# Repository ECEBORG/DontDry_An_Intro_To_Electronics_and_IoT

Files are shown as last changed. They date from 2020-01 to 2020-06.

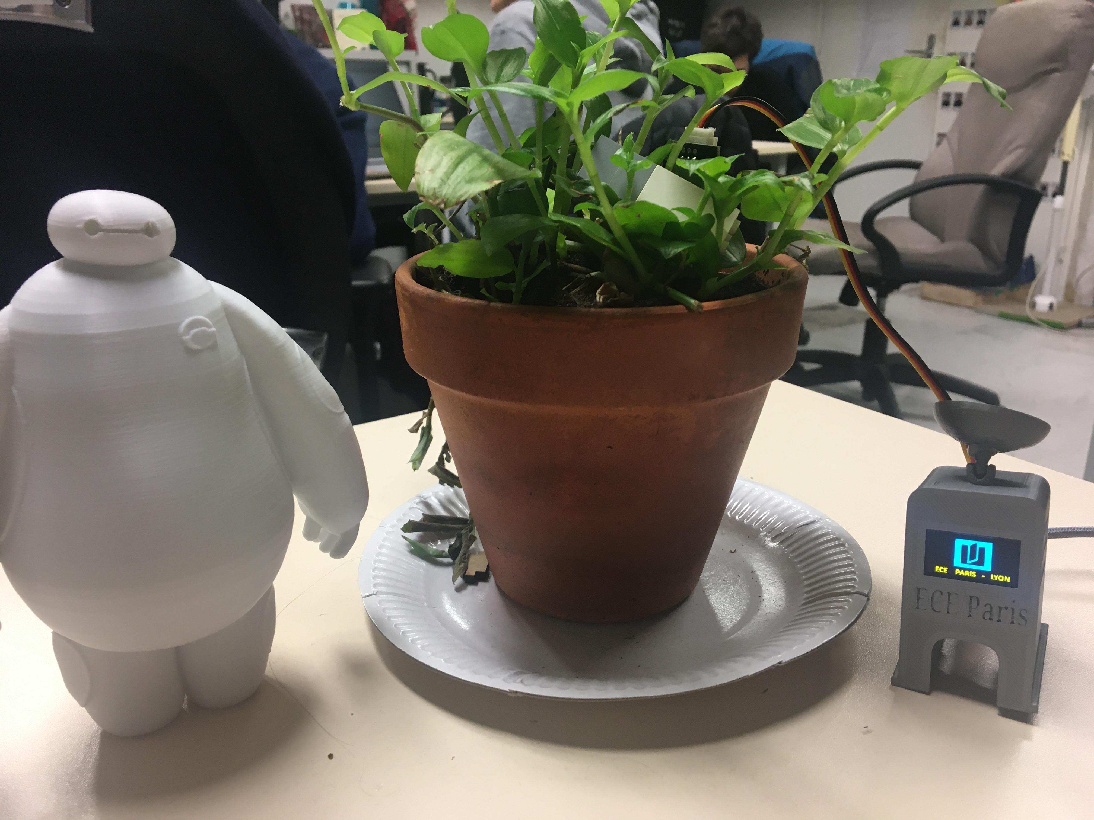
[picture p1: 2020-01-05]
Illustration dont dry.jpg

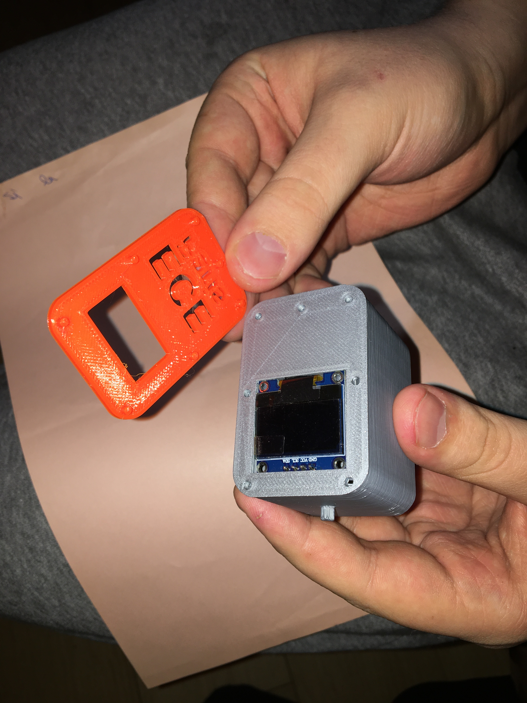
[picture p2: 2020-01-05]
Photos d'illustration/IMG_9418.JPG

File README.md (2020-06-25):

# ECEBORG - Projet "Don't dry"

_Beginner's Electronics project - plant monitoring tool_

> Ce projet a été organisé en Decembre 2019 par Nicolas Chollet avec l'aide de Lucie Pignol, Chloé Leca-Labouillerie, Maelys Bourgeat, Clément Couillerot & Benoit Montazeaud.

Le projet don't Dry est un atelier pour faire découvrir le monde des microcontroleur, de l'IoT et de l'électronique à des débutants.
Il contient trois activités:

* Soudure et montage d'une **petite station connectée permettant de lire la température, l'humidité de l'air et l'humidité du sol**.
* Cours d'introduction aux systèmes embarqués et à l'IoT
* Visite du fablab de l'ece et du hackerspace d'Eceborg

## Dans ce dossier vous trouverez :
* **Administratif** : Tout ce qui est relatif à l'organisation du projet
* **BitMaps** : Les images à afficher sur l'écran du projet
* **Code_Dont_Dry** : Il s'agit du code à flasher sur la carte, il est commenté.
* **STL** : Les fichiers Stl à télécharger pour le boitier
* **Support de présentations** : Les powerpoint utilisés pendant l'introduction, le cours sur les SE et la visite d'Eceborg
* **Tutoriels Arduino & Montage** : Tuto sur l'installation d'Arduino et le montage du projet à partir du Kit
* Un **descriptif de l'atelier**

Pour toute questions n'hésitez pas à contacter Eceborg:
eceborg.paris.bureau@assos.ece.fr
ou sur notre page facebook, twitter, instagram: [@eceborg](https://facebook.com/Eceborg/)

Merci beaucoup!

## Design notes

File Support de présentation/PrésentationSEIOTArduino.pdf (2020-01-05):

## UNE INTRODUCTION AU MONDE DES SYSTEMES

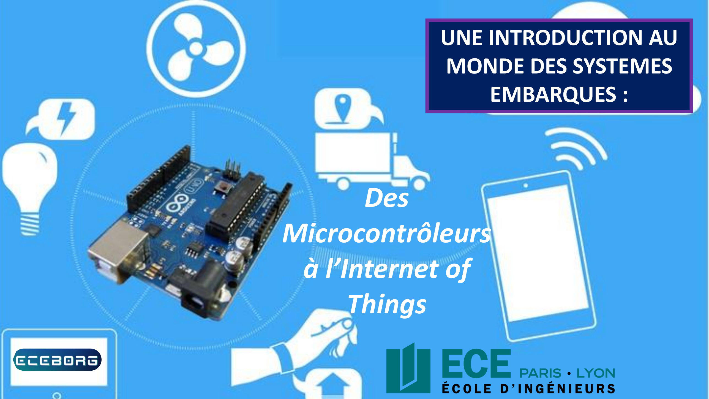
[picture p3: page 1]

## EMBARQUES :

# Des Microcontrôleurs à l’Internet of Things

# Système embarquoi?

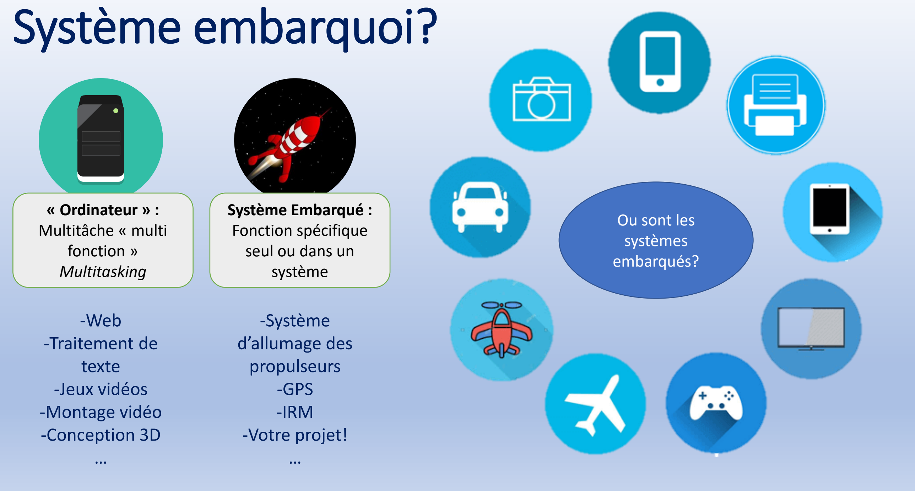
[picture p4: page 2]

Ou sont les
systèmes
embarqués?

« Ordinateur » :
Multitâche « multi
fonction »
Multitasking

Système Embarqué :
Fonction spécifique
seul ou dans un
système

-Web
-Traitement de
texte
-Jeux vidéos
-Montage vidéo
-Conception 3D
…

-Système
d’allumage des
propulseurs
-GPS
-IRM
-Votre projet!
…

# Internet

Of

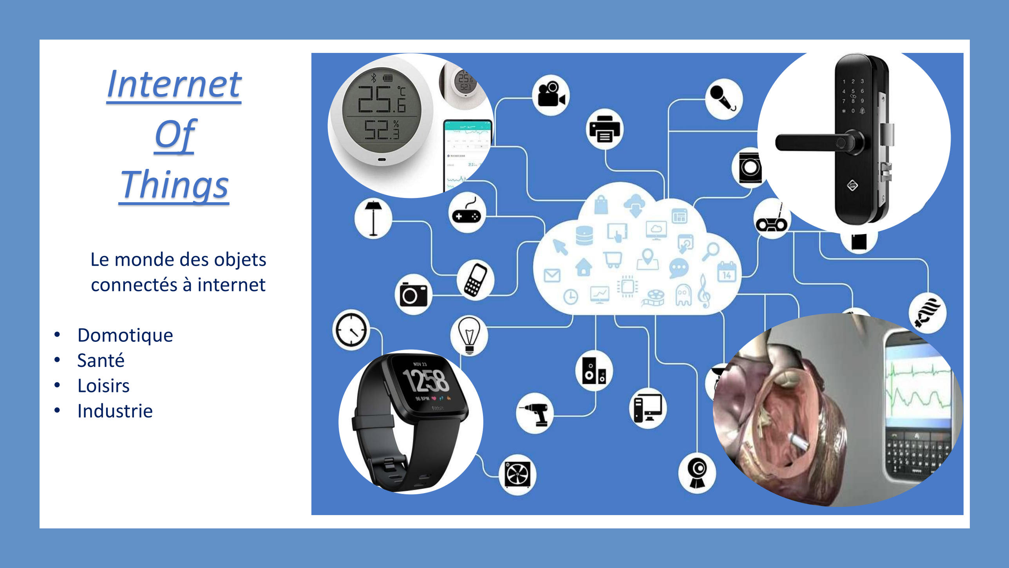
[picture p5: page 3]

# Things

Le monde des objets
connectés à internet
- Domotique
- Santé
- Loisirs
- Industrie

## La troisième révolution du Web

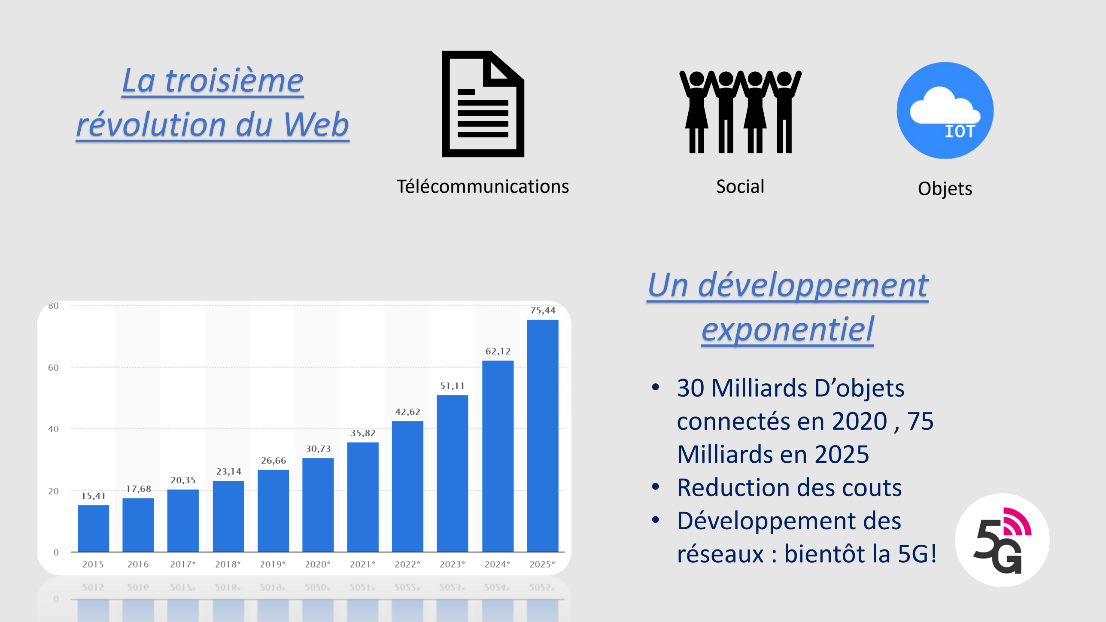
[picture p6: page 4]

### - 30 Milliards D’objets connectés en 2020 , 75 Milliards en 2025 - Reduction des couts - Développement des réseaux : bientôt la 5G!

## Un développement exponentiel

Télécommunications | Social | Objets

## MCU: MicroController Unit : Microcontrôleur

## CPU: Central Processing Unit

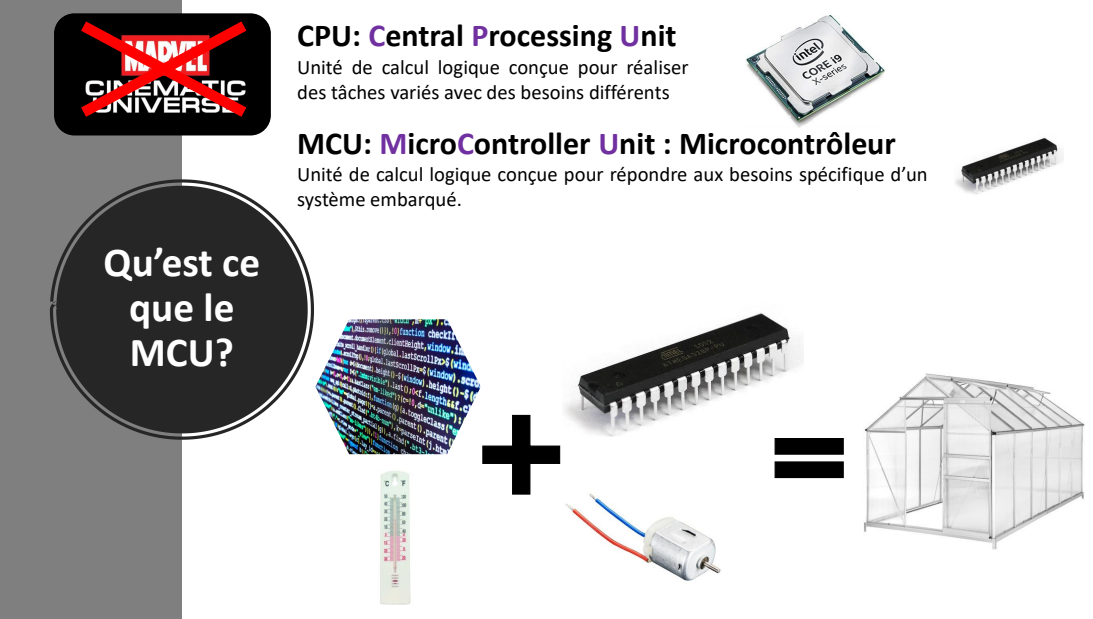
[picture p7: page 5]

Unité de calcul logique conçue pour réaliser
des tâches variés avec des besoins différents

Unité de calcul logique conçue pour répondre aux besoins spécifique d’un
système embarqué.

Qu’est ce
que le
MCU?

# La genèse d’Arduino

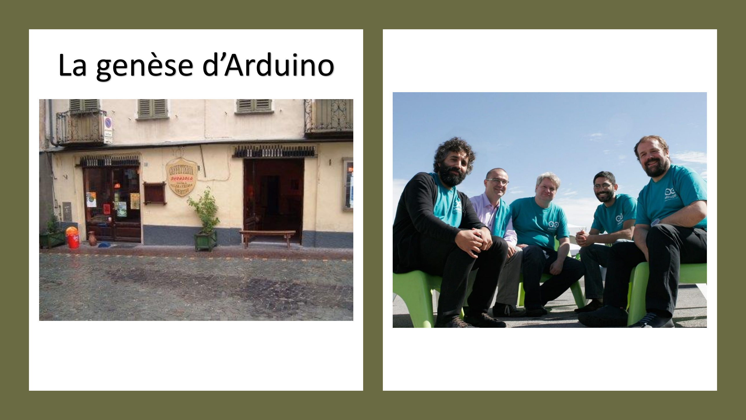
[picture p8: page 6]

# L’Arduino ou le microcontrôleur

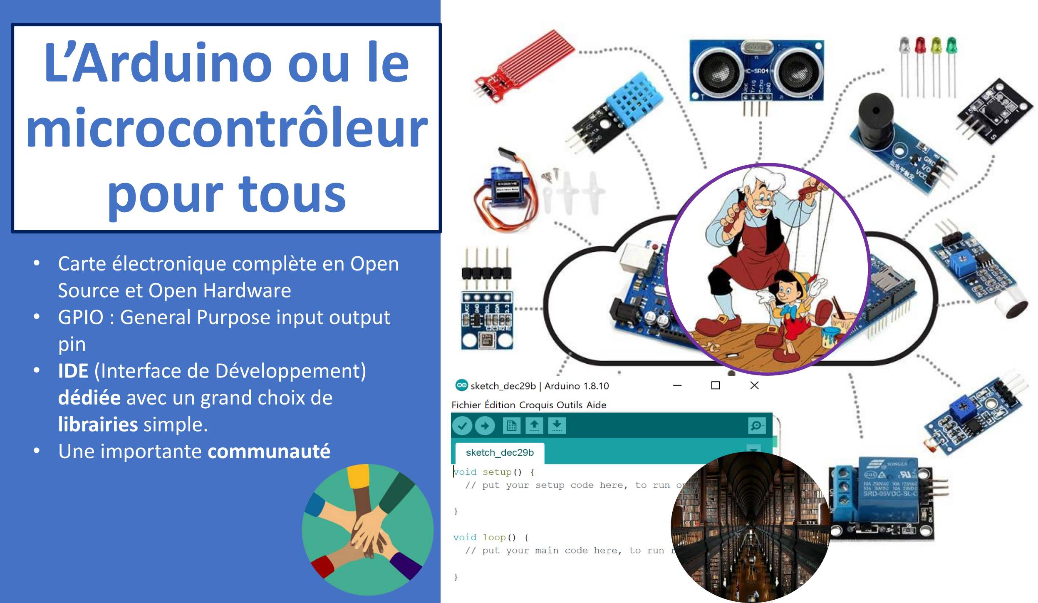
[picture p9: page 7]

# pour tous

- Carte électronique complète en Open Source et Open Hardware
- GPIO : General Purpose input output pin
- IDE (Interface de Développement) dédiée avec un grand choix de librairies simple.
- Une importante communauté

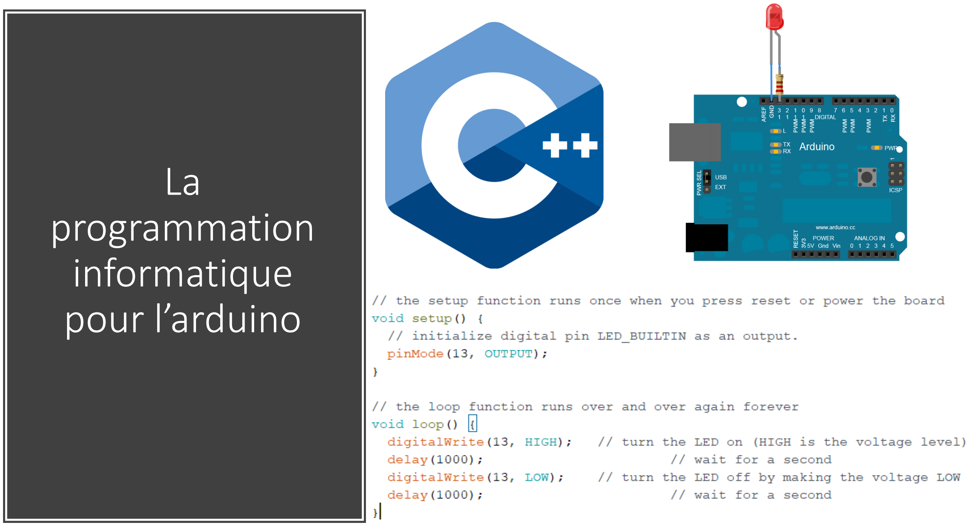
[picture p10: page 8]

La

# programmation informatique pour l’arduino

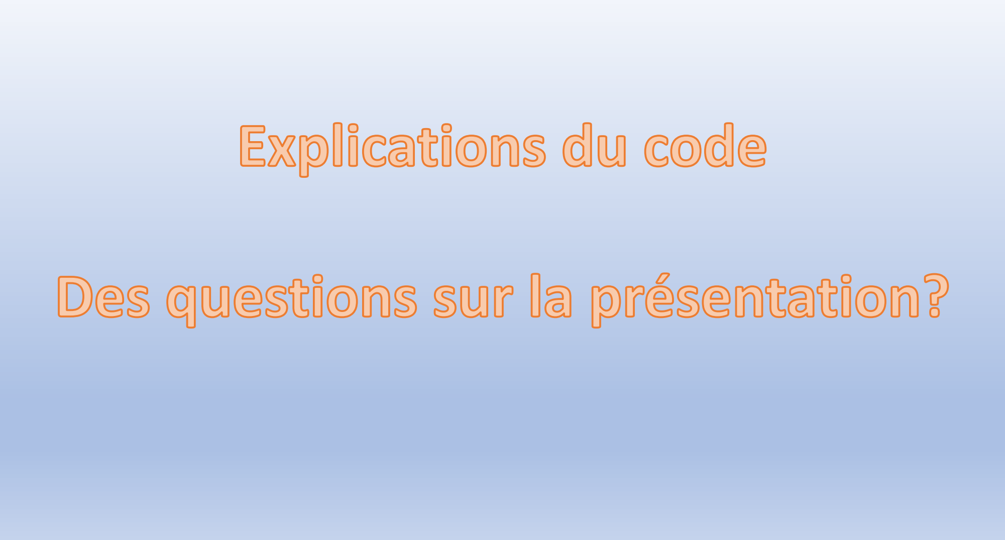
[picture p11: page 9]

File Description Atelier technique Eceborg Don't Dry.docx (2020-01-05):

Atelier technique Eceborg

Session admission 2020

Don’t Dry

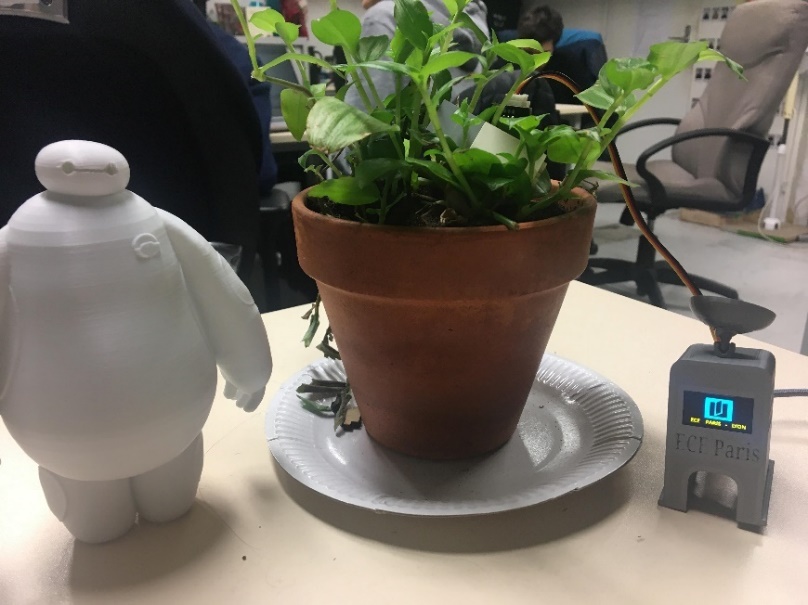
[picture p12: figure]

# I. Objet de ce document

Ce document a pour but de fournir des explications claires et précises concernant la réalisation du projet « don’t dry » dans le cadre des sessions admissions de 2020. Il est destiné aux organisateurs de cet atelier.

# II. Introduction

En Janvier et Février 2020, l’ECE organise trois sessions admissions où l’école accueille 180 élèves de terminale et première afin de leur faire découvrir l’école (60 par session). Dans ce contexte, Eceborg a été sollicité pour réaliser un atelier créatif pour initier ces élèves à l’électronique et au travail d’ingénieur. Cet atelier invite les participants à construire leur propre station connectée pour les aider à la gestion de l’arrosage d’une plante plante afin de découvrir le monde de l’IoT (Internet Of Things). Cet objet sera capable de :

- Afficher la température ambiante
- Afficher l’humidité de l’air
- Indiquer s’il faut arroser la plante ou non
- Indiquer l’heure
- Fournir ces informations via un site web local
- Envoyer une alerte mail quand il faut arroser la plante

L’idée est de fournir le code et le matériel aux élèves et de les accompagner pour les soudures, l’assemblage et le flashage du code.

# III. Description technique du projet

## A. Composants

- Microcontrôleur : Wemos D1 mini

Datasheet: https://wiki.wemos.cc/products:d1:d1_mini

Ce microcontrôleur fonctionne comme un Arduino mais dispose d’une puce esp8266 qui lui permet de se connecter en Wifi.

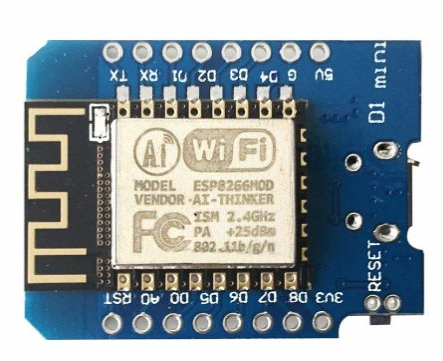
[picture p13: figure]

- Ecran : Afficheur OLED 0,96'' contrôlé en I2C

Datasheet : https://cdn-shop.adafruit.com/datasheets/SSD1306.pdf

Cet écran permet d’écrire sur 4 lignes différentes lisiblement.

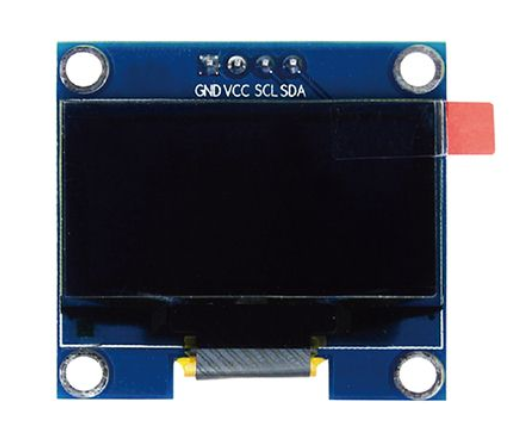
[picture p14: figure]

- Capteur d’humidité et de température : DHT11

Datasheet : https://www.mouser.com/datasheet/2/758/DHT11-Technical-Data-Sheet-Translated-Version-1143054.pdf

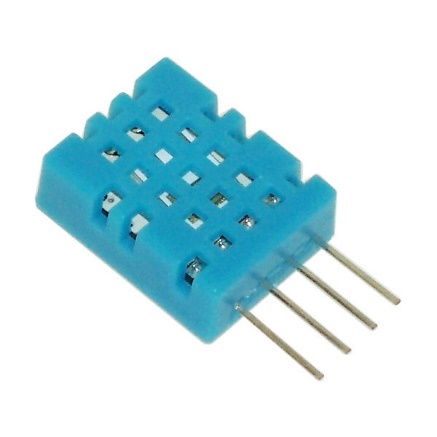
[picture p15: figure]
Résultat de recherche d'images pour "dht11"

- Capteur d’humidité des sols :

Datasheet : https://www.electroschematics.com/arduino-soil-moisture-sensor-module/

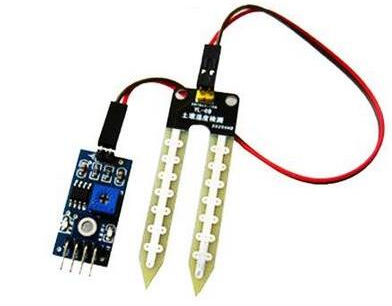
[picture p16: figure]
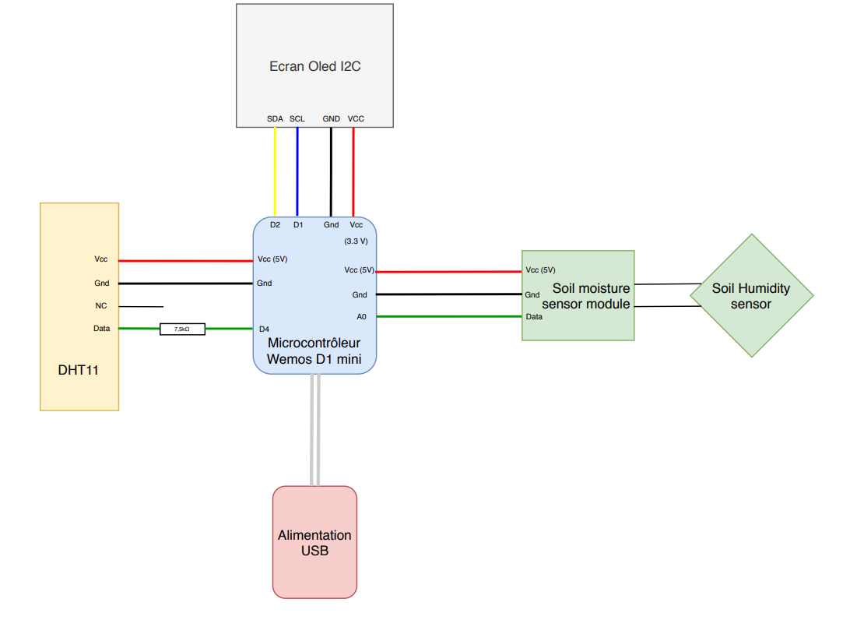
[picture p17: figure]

## B. Schéma fonctionnelle

Ce schéma représente les connections à effectuer entre les différents composants. Chaque fil a un code couleur et sera fourni avec les composants déjà découpé à la bonne taille. Il suffira juste de souder chaque fil à l’endroit indiqué.

Attention ce schéma contient une erreur au niveau des Pins de la DHT11. Regardez google pour la position exact des pins et de la résistance (en pull up).

## C. Code

Le Code est déjà réalisé et commenté. Il est communiqué en annexe de cette présentation. Pour sa bonne exécution il faut installer plusieurs librairies :

- Adafruit_SSD1306.h : Bibliothèque de fonctions pour l'écran Oled 128x64
- DHT.h : Bibliothèque de fonctions pour le capteur de température et d'humidité DT11
- NTPClient.h : Bibliothèque pour la gestion de l’heure
- ESP8266WiFi.h : Bibliothèque pour la gestion de la connexion internet
- WiFiUdp.h : Bibliothèque pour la gestion de la connexion internet

Sur ce lien vous pourrez trouver un tutoriel pour installer une librairie sur Arduino :

https://www.arduino.cc/en/guide/libraries

## D. Coque

La coque est imprimée en 3D. Pour le moment un design est proposé aux élèves et potentiellement d’autres seront créés d’ici le début de la session. Toutes les coques sont conçues dans le même but : pourvoir insérer les différents composants en les clipsant de manière simple et rapide. Les coques seront imprimées en amont de la session immersion.

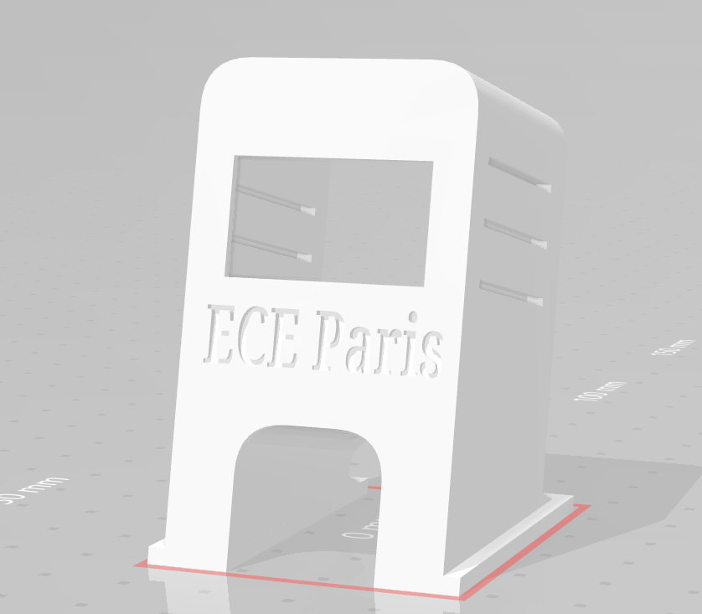
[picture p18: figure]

## E. Résumé

La réalisation du projet se déroule donc en trois étapes :

1. Soudure des composants
2. Flashage du code sur le microcontrôleur
3. Assemblage des composants dans le boitier

# IV. Répartition des élèves.

Les groupes des élèves visitant l’ECE sont composés de 60 élèves. Pour faciliter la mise en place des ateliers ils seront séparés en 4 groupes de 15 élèves qui seront chacun accompagné par 5 accompagnateurs de l’ECE pour la bonne réalisation du projet. Chaque groupe de 15 effectuera le même programme.

# V. Rôle des accompagnants

## A. Organisation globale et déroulement

L’atelier débute à 14H15. Le rendez vous est fixé en P445 ou Nicolas Chollet fera une brève présentation du projet aux 60 élèves ainsi que le déroulement de l’atelier. Après la présentation, les élèves seront emmenés par groupe de 15 par 5 accompagnateurs. Chaque groupe dispose d’une salle dans laquelle sera installé une paillasse pour les travaux d’électronique.

Dans chaque groupe de 15 donc, les élèves devront alterner entre trois ateliers en groupe de 5 :

- Atelier électronique 40 minutes : soudure des composants, dans la salle du groupe.
- Atelier informatique 40 minutes : explication du monde de l’Arduino (20 min) puis explication du code et flashage du code sur les cartes (20min), dans la salle du groupe.
- Atelier découverte du fablab et d’Eceborg (40 min) : Visite du fablab (20 min), visite du hackerspace d’ECEborg (20 min).

Pour conclure tous les groupes seront ramené à 16H30 dans la P445 pour un mot de conclusion de la part de Nicolas Chollet.

## B. Electronicien

Les accompagnateurs électroniciens auront la charge de l’atelier électronique. Ils seront deux par salle (8 au total). Leur rôle est d’accompagner 5 étudiants à la fois pour réaliser toutes les soudures en 40 min pour les 5 étudiants et de finir les soudures de ceux qui n’auraient pas été assez rapide. Ils disposeront d’un document imprimé précisant chaque étape avec photos et indications pratique. Ces accompagnateurs seront également formés en réalisant une première fois l’atelier en amont du jour J.

Profil recherché pour le poste électronicien : 2 personnes

- Sait faire des soudures ou est prêt à apprendre
- Disponible à un moment pendant les vacances de noël pour venir réaliser le projet (du coup on repart avec le projet).
- Manuel (enfin un minimum mais encore une fois c’est très basique juste quelques soudures)

## C. Chef de salle

Le rôle du chef de salle est minime il accompagne juste les élèves jusqu’à leur salle après l’introduction en p445, il est attentif au timing. A la fin des ateliers il rassemble les 15 élèves de sa salle et les raccompagne en p445. Le chef de salle n’est pas un rôle à 100% et il vient s’ajouter à un autre rôle (électronicien ou informaticien)

## D. Informaticien

Les accompagnateurs informaticiens réalisent une présentation PowerPoint sur l’Arduino, les microcontrôleurs et le code en C++. Ils sont au nombre de deux. La présentation est composée de slides qui leur seront fournies ainsi que les informations à communiquer à chaque slide. La présentation dure 20-25 minutes en fonction des questions. Par la suite ils réalisent une démo pour montrer l’installation de l’IDE Arduino et explique rapidement le code du projet en indiquant les parties que les élèves peuvent modifier chez eux. Enfin ils flash le code sur les microcontrôleurs des élèves.

Ces élèves assisteront en amont à la présentation pour bien comprendre et être capable de la reproduire. Ce sera surement par Skype ou via une vidéo YouTube. Cette présentation sera disponible avant noël.

Profil recherché pour le poste informaticien : 2 personnes

- A l’aise à l’oral
- Capable de ramener son ordinateur le jour de la soutenance
- Connait plus ou moins l’IDE Arduino ou est prêt a subir une petite formation en plus pour bien comprendre.

## E. Guide & Présentateur

Les guides, sont au nombre de deux. Toutes les 40 min il viennent chercher 5 élèves de deux salles différentes soit 10 élèves au total pour les emmener à la visite du fablab puis à la visite de Eceborg. Ils auront un document leur indiquant leur parcours étapes par étapes.

Profil recherché pour les guides :

- Avoir des pieds
- Être jovial pour discuter avec les élèves sur le chemin

Les présentateurs sont au nombre de deux : un a Eceborg et un au fablab. Ils réalisent la présentation de ces deux lieux, plus du mécanisme de l’impression 3D (à eceborg) et de la découpe laser (fablab). C’est à cette occasion qu’ils récupèrent un badge ece découpé au laser ainsi que le boitier pour leur prototype.

Ces rôles seront assurés par Benoit Montazeau (Eceborg) et Sébastien Ye (makers).

## F. Récapitulatif

- Accueil en P445 entre 14H et 14H15
- Présentation du projet + répartition des 60 élèves en 4 groupes de 15 dans 4 salles différentes.
- Répartition des groupes en trois sous-groupes de 5 élèves qui se répartissent sur les trois ateliers dans chaque salle : électronique, informatique, visite et début à 14H30.
- Changement d’atelier toutes les 40 minutes soient à 15H10 et 16H50
- Mot de la fin et conclusion en P445 (10 min) à 16H30.

# VI. Besoins logistiques

Chaque salle a besoin :

- 1 Projecteur
- 4 fers à souder
- 1 bobine d’étain
- 15 kits du projet Don’t Dry
- 1 pinces à dénuder
- 1 pompe à dessouder + du fil à dessouder
- 1 seringue de flux
- 4 troisièmes mains
- 3 pinces plates
- 2 pinces coupantes
- 1 ensemble de gaine thermo rétractable.
- 1 kit de fils
- Des feuilles & stylo

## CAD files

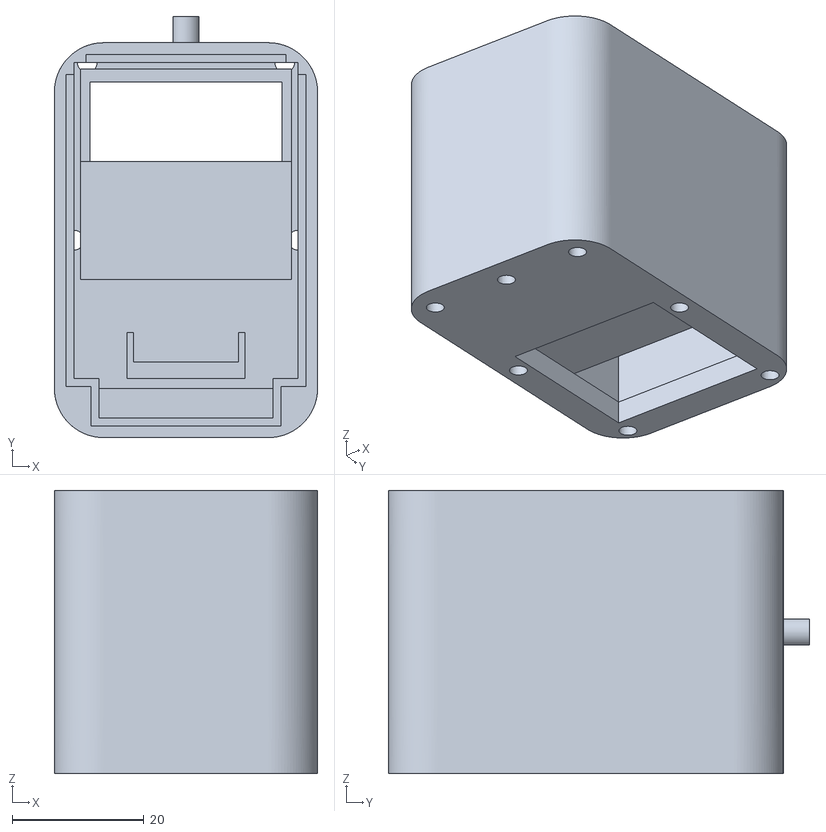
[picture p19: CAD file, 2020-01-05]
STL/Body.stl
40.0 x 64.0 x 43.0

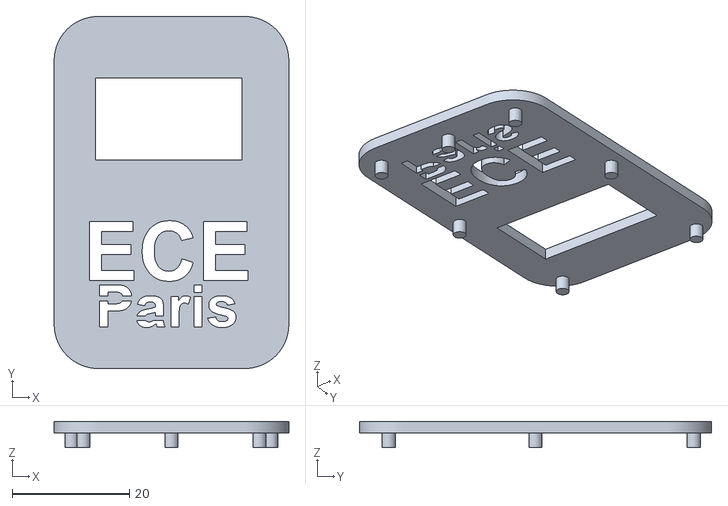
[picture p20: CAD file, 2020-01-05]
STL/front.stl
40.0 x 60.0 x 4.50

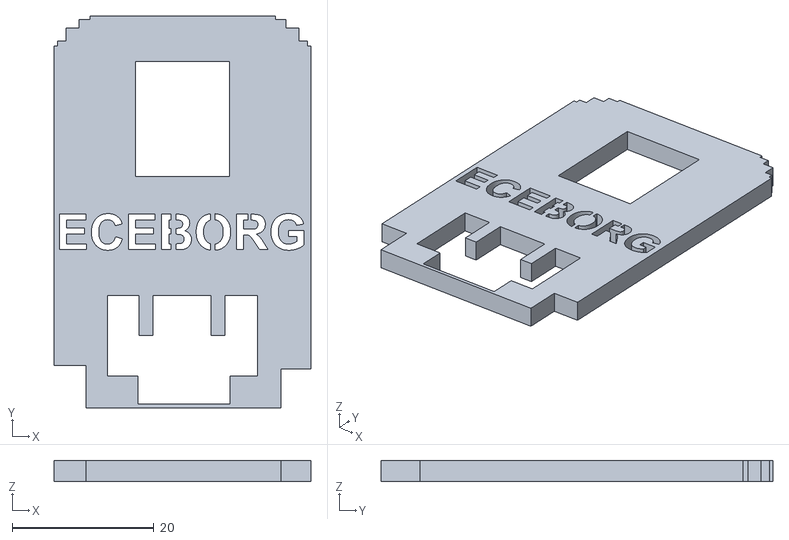
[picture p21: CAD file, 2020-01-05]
STL/BACK.stl
36.2 x 55.2 x 3.00

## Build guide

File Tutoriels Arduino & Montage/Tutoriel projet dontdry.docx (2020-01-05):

Tutoriel projet don’t dry

# Outils à disposition sur la paillasse :

- 3 fers à souder
- 1 bobine d’étain
- 1 seringue de flux
- 1 éponge métallique
- 1 pince à dénuder (un peu difficile donner juste un coup sec et rapide, s’entrainer sur un fil avant)
- 1 pince coupante
- 1 pince plate
- 1 pince de précision
- 2 troisième main
- Fil 5 couleurs : jaune bleu vert rouge noir
- Cyanoacrylate (Superglue)
- 1 pistolet à colle
- De la gaine thermo rétractable de diamètre 1,2 et 3 mm

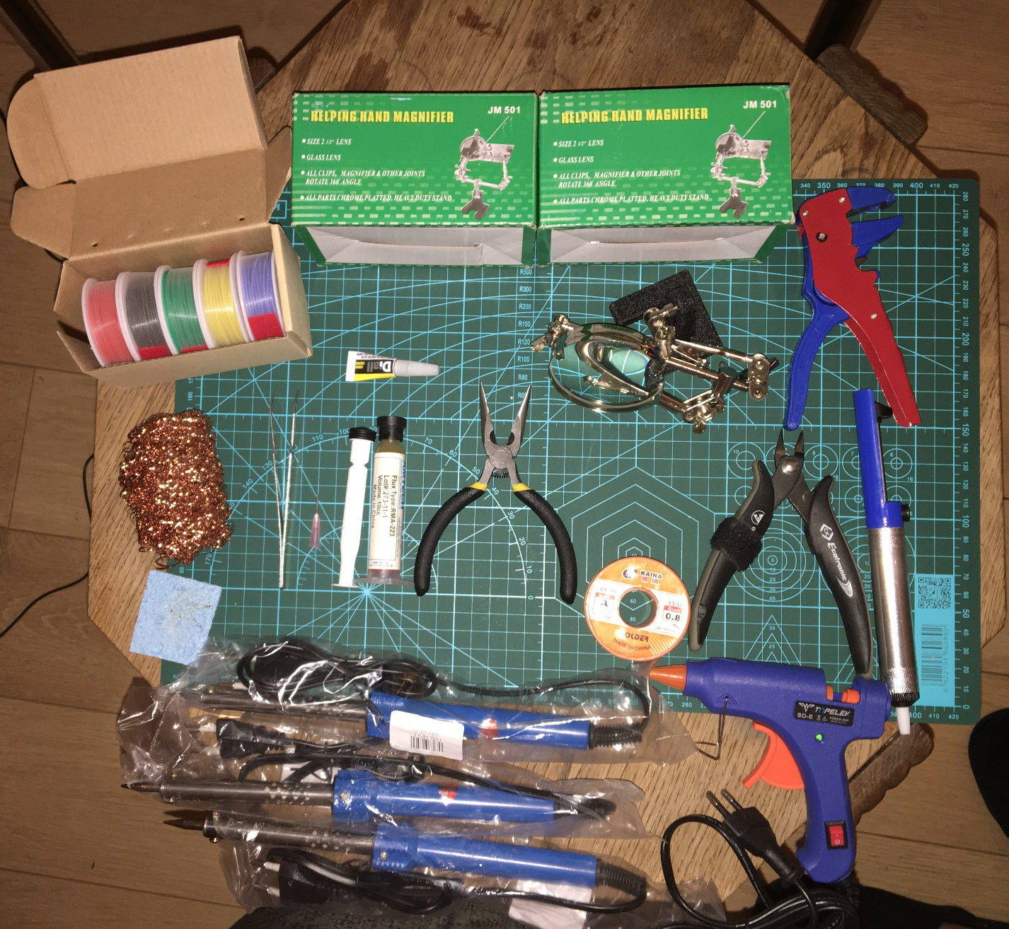
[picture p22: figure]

# Contenu d’un kit :

- 1 boitier
- 1 face avant
- 1 face arrière
- 1 microcontrôleur Wemos D1
- 1 écran avec fils déjà soudés
- 1 capteur d’humidité des sols avec fils déjà soudés
- 1 capteur de température
- 2 dominos
- 1 chargeur micro USB

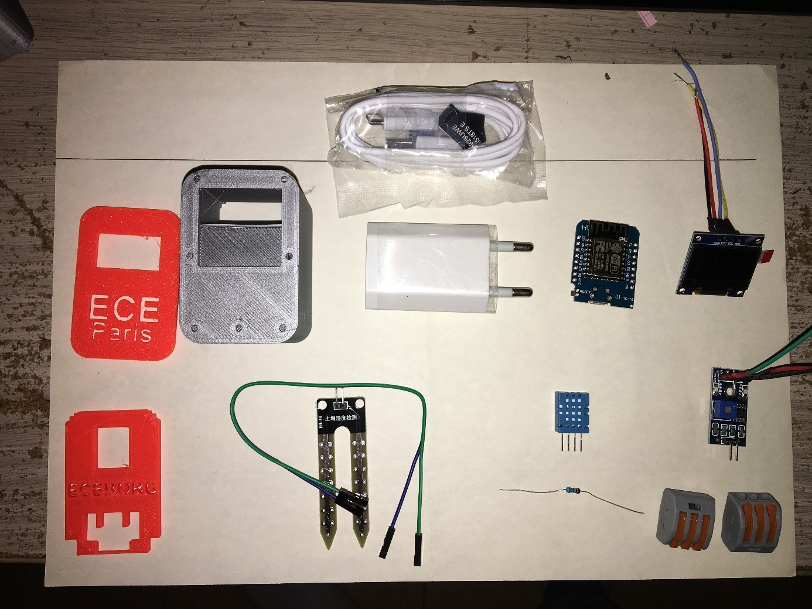
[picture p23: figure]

Etape 1 : Soudure du DHT11

Sur le DHT11 une pin ne sert à rien c’est celle du milieu droit. On peut le couper.

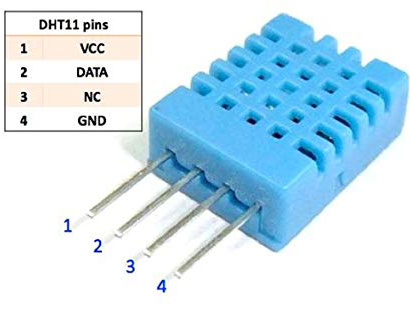
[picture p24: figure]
Résultat de recherche d'images pour "dht11"

On soude donc des fils d’environ 5 cm au pin : Un fil noir à la pin de ground 4, Un fil rouge à la pin de power 1, et un fil de data vert à la pin de data 2.

Par la suite passe un morceau de gaine thermo rétractable sur chaque pin pour éviter les cours circuits.

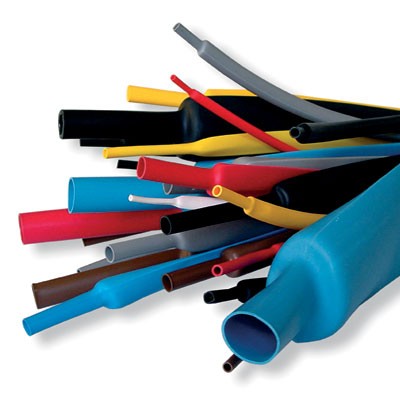
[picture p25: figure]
Résultat de recherche d'images pour "thermoretractable"

Etape 2 : Soudure des composants au microcontrôleur

On soude ensuite les différents composants au microcontrôleur comme sur le schéma ci-dessous :

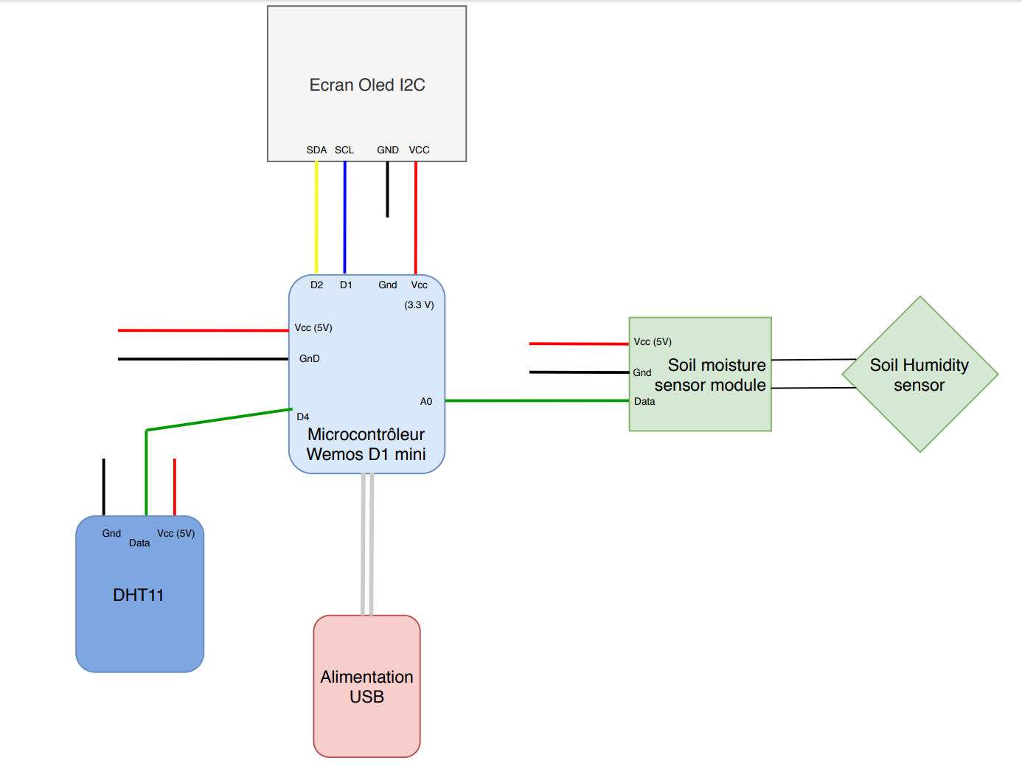
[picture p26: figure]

Attention a l’orientation du microcontrôleur

Il faut que vous soudiez les fils pour qu’ils sortent du côté ou le gros rectangle argenté se trouve comme ceci :

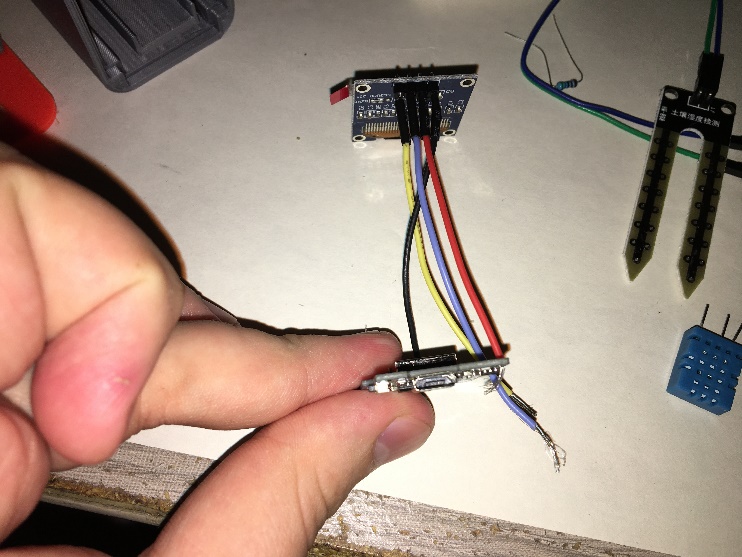
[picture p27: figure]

Car dans le boitier il faut que le microcontrôleur soit comme ceci :

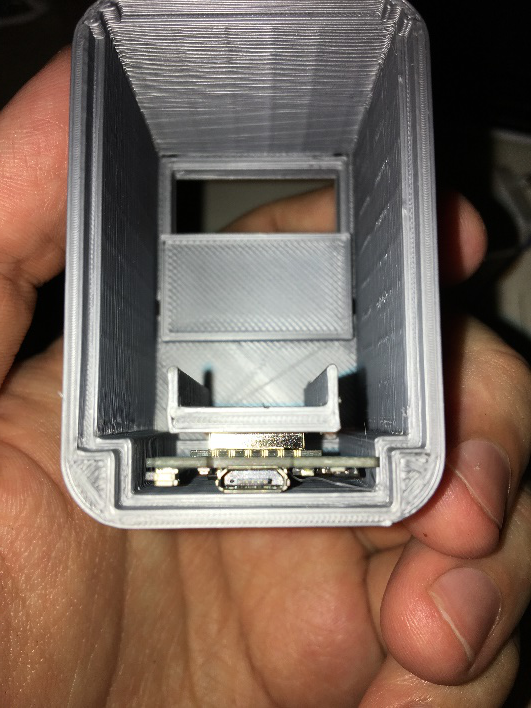
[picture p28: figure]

Ecran :

- La pin de power rouge au 3.3V
- La pin de SDA avec le fil jaune à la pin D2
- La pin de SCL avec le fil bleu à la pin D1

Humidité des sols :

- La pin de data fil vert à la pin A0

Température & Humidité :

- La pin de Data avec le fil vert à la pin D4

Fils :

- Un fil noir de 5 cm environ à la pin de ground du MCU
- Un fil rouge de 5 cm environ à la pin de +5V du MCU

Etape 3 : Liaison Domino

On relie ensuite tous les fils noirs de grounds libre et tous les fils rouge de power libre à l’aide de deux dominos comme ceci : (le jour j les dominos pourront être un peu différents). Pour se servir de ceux-ci soulevez les languette poussez le fil dénudé jusqu’au fond et rabaisser la languette. C’est bon si les fils sont bien coincés. On peut mettre plusieurs fils par trous.

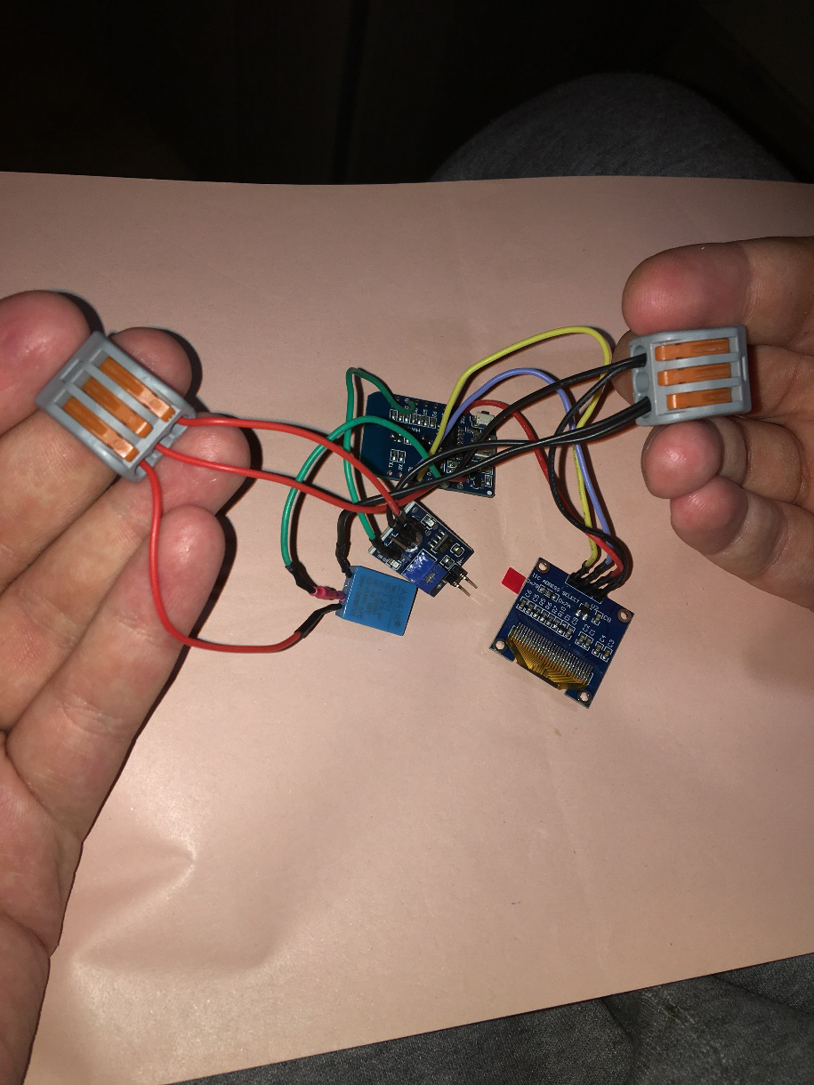
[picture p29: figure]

Etape 4 : Mise en place des composants dans le boitier.

Pour mettre en place les composants commencez par faire passer l’écran par l’arrière du boitier et le clipser dans la face avant :

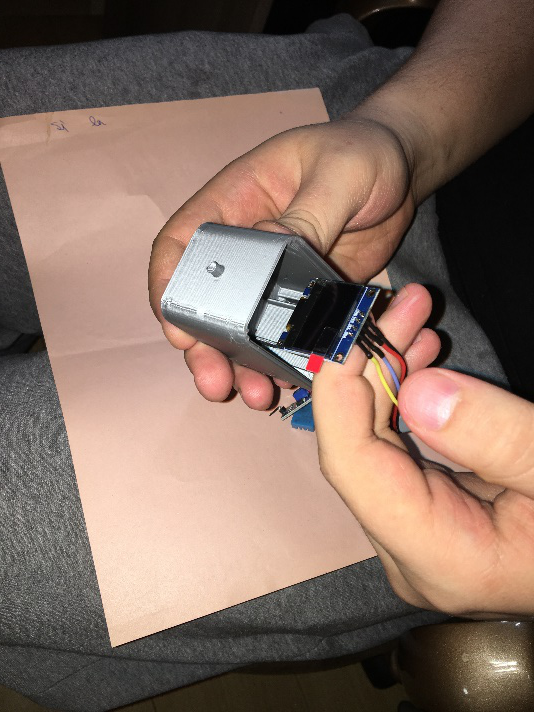
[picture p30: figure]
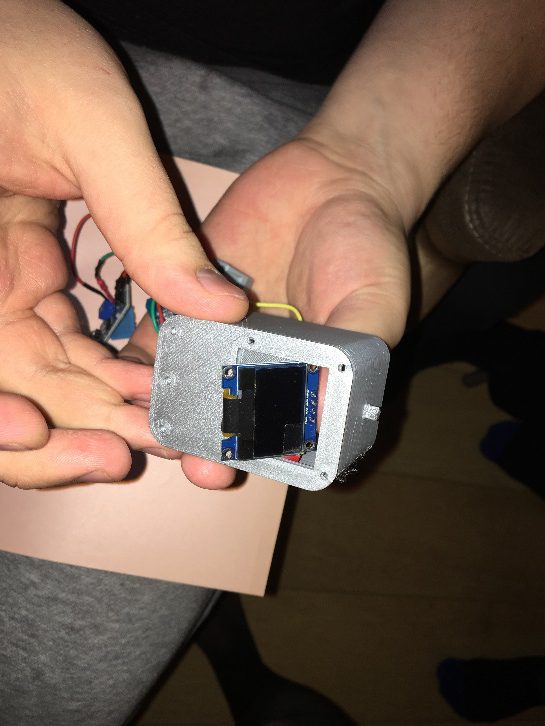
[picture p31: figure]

Par la suite faire passer le microcontrôleur sous la languette par l’arrière du boitier et positionner le capteur d’humidité des sols sur la languette comme ceci : ATTENTION SUR LA PHOTO LES FILS ONT ETE SOUDEES DANS LE MAUVAIS SENS SUR LE MICROCONTROLEUR. Celui-ci n’est donc pas à l’endroit, bien souder les fils comme indiqué ci-dessus..

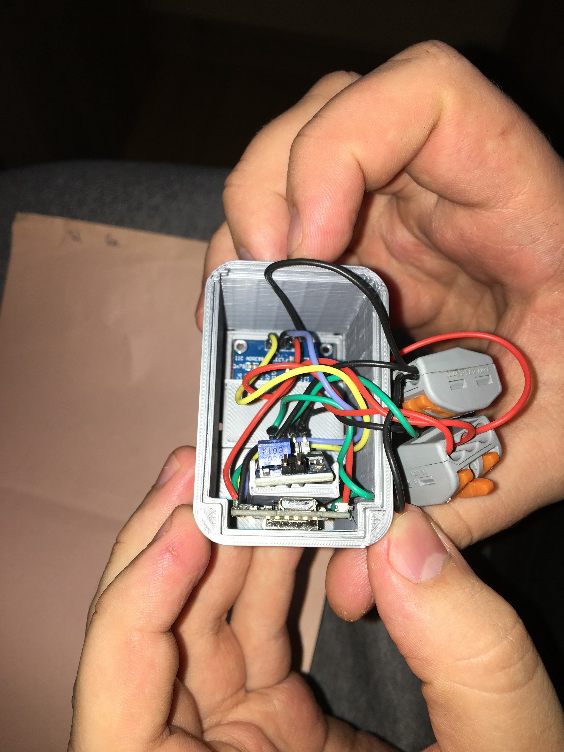
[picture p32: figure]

Ensuite on clips le DHT11 dans le couvercle du dos on pousse les dominos dans le boitier et on clips le couvercle.

Attention avant de clipser le couvecle il faut couper la partie du bas comme ceci :

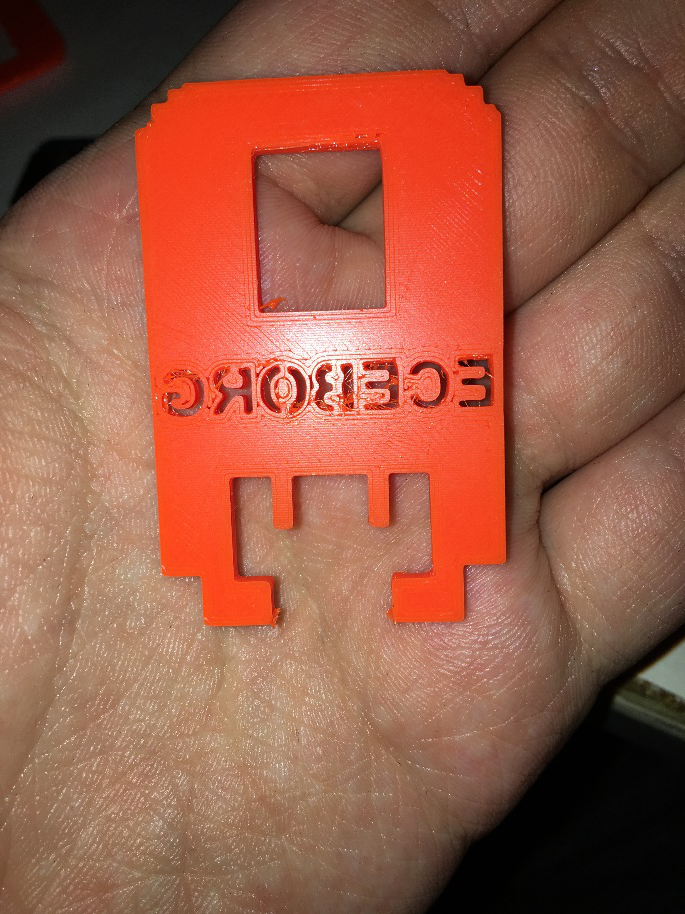
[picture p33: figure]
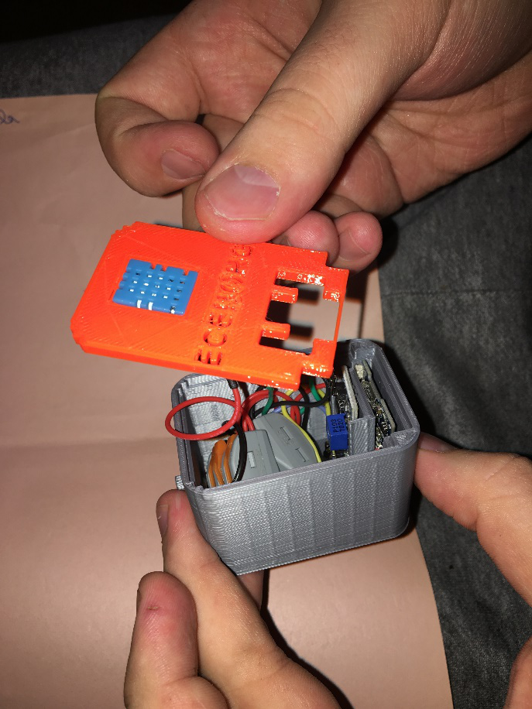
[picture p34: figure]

Pour finir on clipse la face avant (rajouter de la glue si cela ne tient pas bien) :

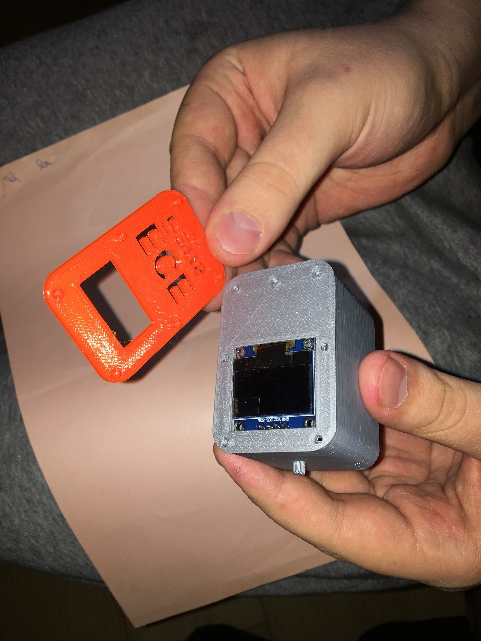
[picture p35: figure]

Enfin on branche aux pins du capteur d’humidité le capteur d’humidité des sols.

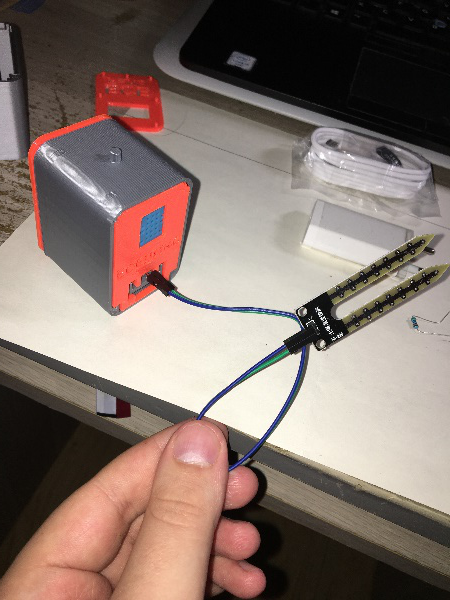
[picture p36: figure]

Et voila !

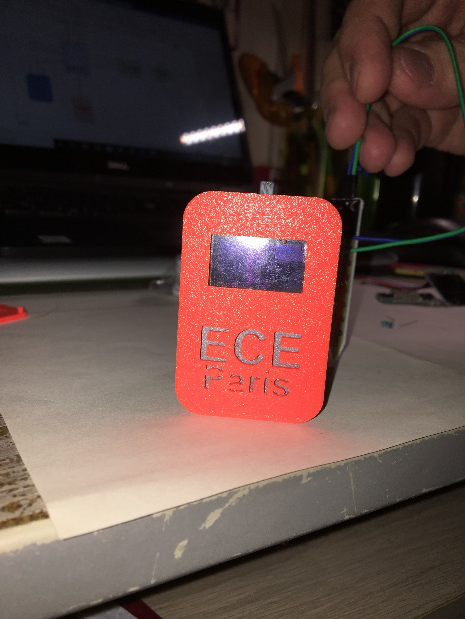
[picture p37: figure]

Etape 5 : Flash du code personnalisé

Quand vous avez terminez, demander à ce qu’on vous flash le code !

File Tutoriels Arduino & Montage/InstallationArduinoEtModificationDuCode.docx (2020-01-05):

# TUTO Don’t Dry chez toi :

I. Installer Arduino & les librairies nécessaires
A. Télécharger l’installateur

Aller sur le site :https://www.arduino.cc/en/main/software

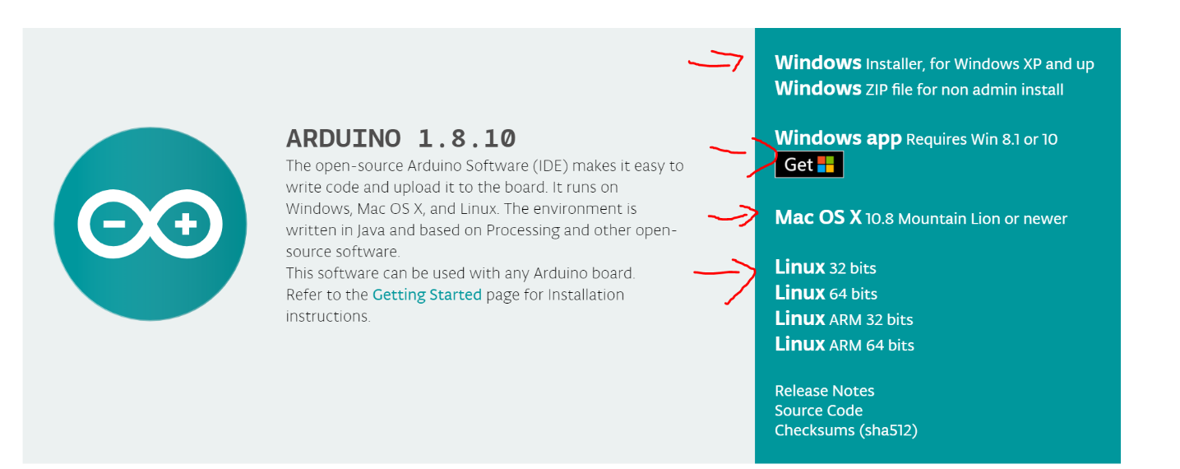
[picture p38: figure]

Télécharger la version qui correspond à votre machine :

Si vous avez Windows 8.1 ou plus vous pouvez également télécharger l’application directement depuis le Windows store.

L’application est gratuite mais vous pouvez faire un don pour soutenir le projet Arduino. Pour installer cliquez sur « just dowload »

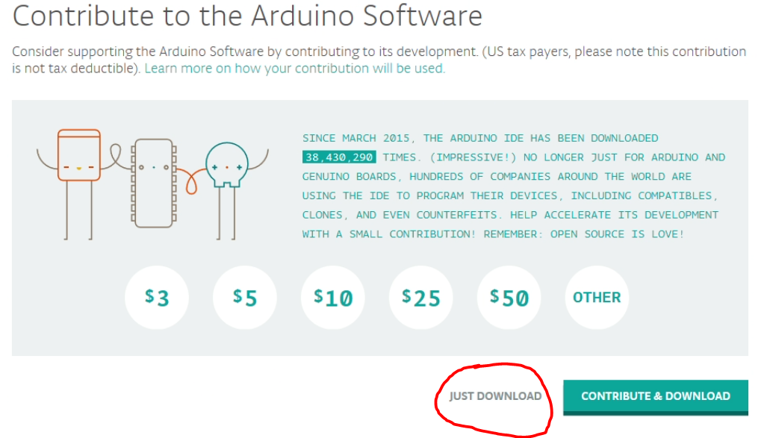
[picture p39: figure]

Pour la suite de ce tutoriel nous serons sur un système d’exploitation Windows. Pour MAC OS suivre ce tutoriel : https://wiki.mdl29.net/lib/exe/fetch.php?media=robotsarduino:installer_arduino_sur_un_mac.pdf

B. Exécuter l’installateur

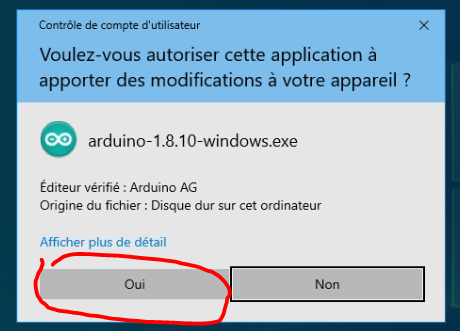
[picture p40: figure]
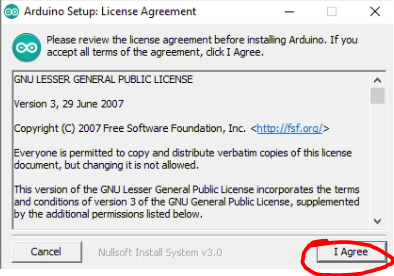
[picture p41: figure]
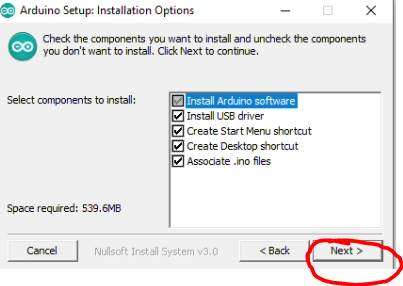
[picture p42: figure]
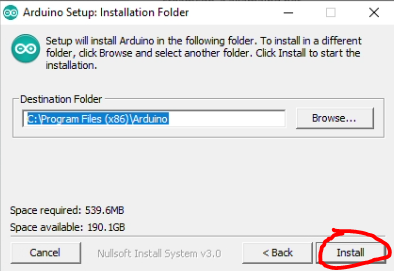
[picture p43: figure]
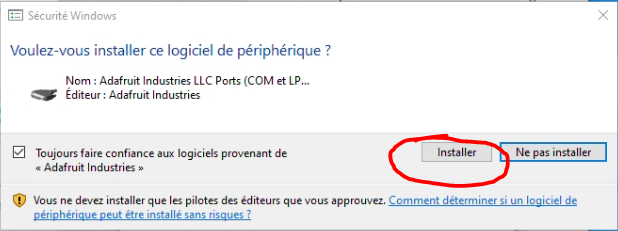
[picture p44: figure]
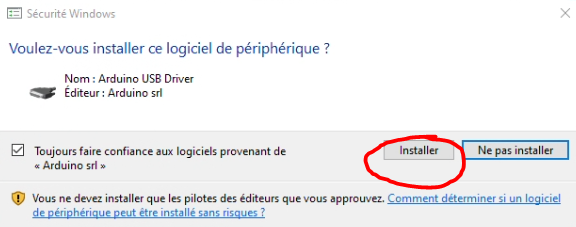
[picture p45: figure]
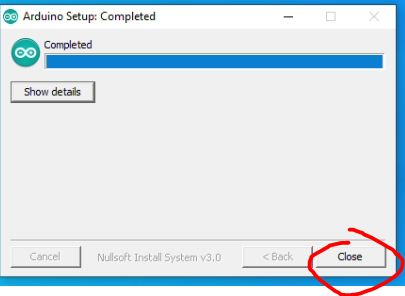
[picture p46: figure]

C. Installation des Librairies :

Une fois l'IDE installé, ouvrez le et rendez-vous dans les préférences (onglet fichier) . Dans la case "Url de gestionnaire de cartes supplémentaires", entrez l'adresse suivante :

http://arduino.esp8266.com/stable/package_esp8266com_index.json

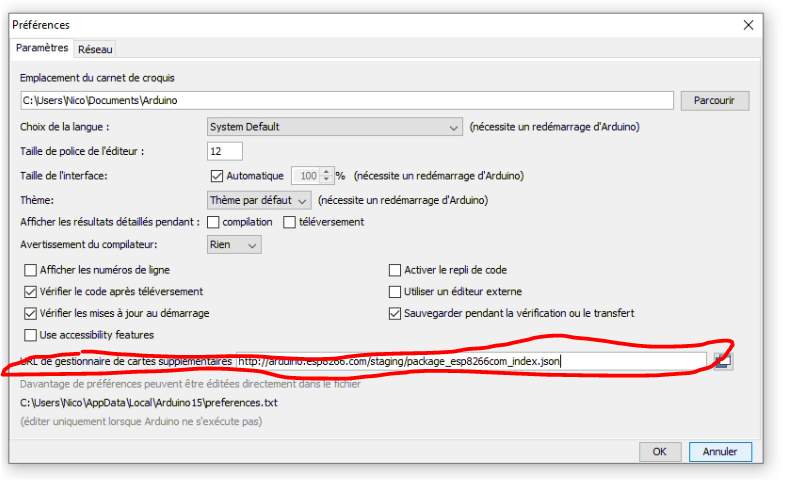
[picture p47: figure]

Puis aller dans Outils>Type de carte>Gestionnaire de carte

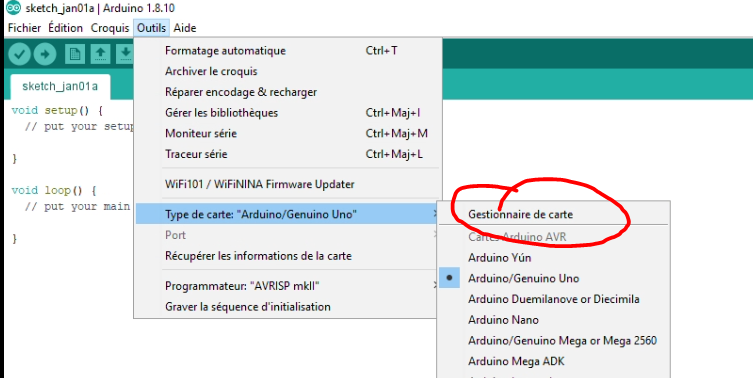
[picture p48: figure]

Puis installer la carte esp8266

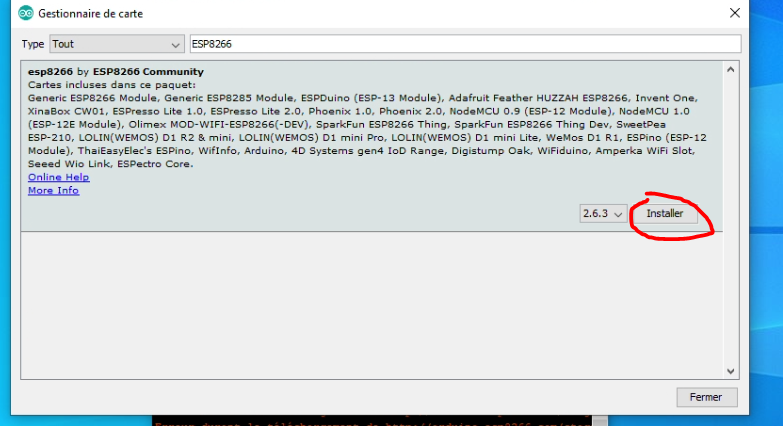
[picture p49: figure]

Ensuite aller dans Outils>Gestionnaire de biliothèque et installer les librairies suivantes :

Adafruit_SSD1306 (librairie pour l’écran) (installer toutes les librairies nécessaires quand demandé)

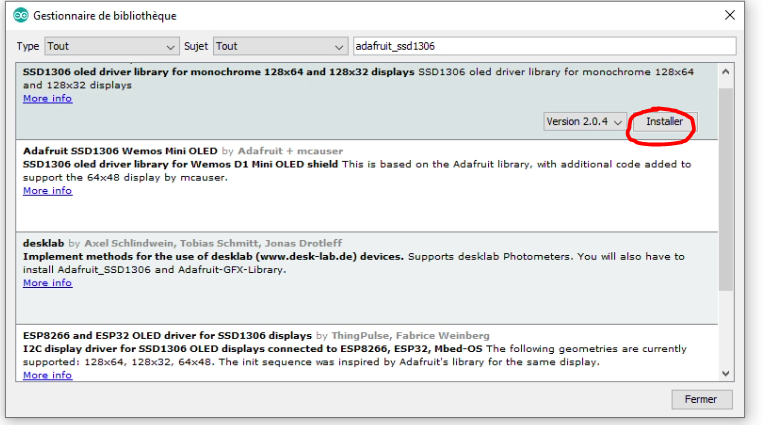
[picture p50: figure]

DHT : (installer toutes les librairies nécessaires quand demandé)

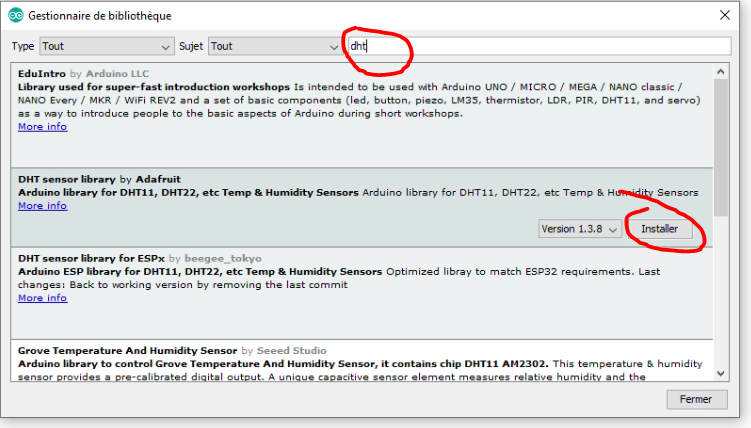
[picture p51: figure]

NTP Client :

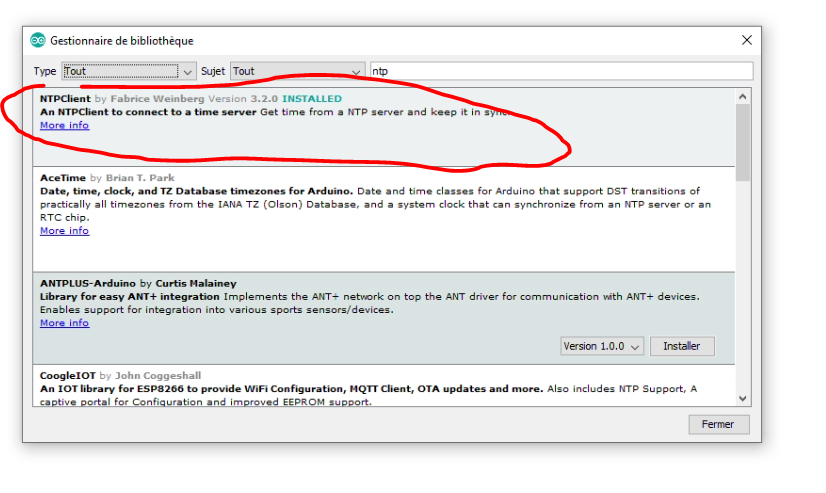
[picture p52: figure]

ATTENTION : Si le code ne compile pas après avoir installé toutes les librairies indiquées, peut être qu’il vous manque une librairies : le compilateur va alors vous dire library missing et le nom de la librairies manquante. Télécharger alors la ou les librairies manquantes comme ci-dessus. Si jamais le problème persiste contactez-nous !

II. Modifier le code

Vous pouvez modifier le code comme bon vous semble pour faire vos propres projets avec la station connecté. En découvrant le monde de l’Arduino vous pourrez par exemple envoyer des messages à afficher sur l’écran, héberger vos propres sites webs, et bien d’autre. Cet atelier n’est qu’une introduction donc si cela vous à plus n’hésitez pas à continuer ! Pour vous aider, vous pouvez compter sur une forte communauté en ligne, des vidéos youtubes, des sites dédiés des forums… Vous trouverez tout cela en cherchant par mots clefs sur votre moteur de recherche favoris. Un conseil : N’hésitez pas à faire vos recherches en anglais ! En effet les communautés y sont beaucoup plus importantes que les francophones ! Vous y trouverez donc beaucoup plus de ressources, conseils, tutoriels…

Pour maintenant retenez juste les quelques lignes de code à modifier pour faire fonctionner votre station avec la Wifi de chez vous et de manière optimale :

- Changer le code Wifi :

Localisez ces lignes et remplacez entre les guillemets par le nom et le mot de passe de votre wifi :

- Changer le nom à afficher au début

Changez le nom entre les guillemets.

- Changer la valeur du capteur d’humidité des sols.

Ici vous allez devoir calibrer le capteur d’humidité des sols afin que celui-ci correspondent au pot dans lequel vous le mettez. Le mieux c’est de tester en changeant les valeurs à laquelle le sol est considéré sec et la valeur à laquelle il est considéré humide en fonction de vos tests.

III. Téléverser sur la carte

Enfin après avoir modifier le code il faut l’envoyer sur la carte. Pour ce faire allez dans Outils>Type de Carte > puis choisir « Lolin Wemos D1 R2 & Mini »

Ensuite aller dans Outils>Ports et choisissez le port sur lequel vous avez branché votre station connecté (celui qui s’affiche quand vous la branché et qui disparait quand vous le débranché.

Enfin appuyer sur la flèche téléverser en haut à gauche:

Vous pouvez rencontre des problèmes lors du téléversement : Les solutions simples sont souvent de :

- Changer de câble
- Redémarrer son ordinateur
- Fermer tous les autres logiciels

Merci d’avoir participé à cet atelier :

Vous pourrez retrouver toutes les ressources nécessaires et ce tutoriel sur le lien de notre Git :

https://github.com/ECEBORG

Dans l’onglet : Projet dont dry

Une question un problème ?

eceborg.paris.bureau@assos.ece.fr

Ou bien plus simple : Facebook, Insta twitter : @eceborg

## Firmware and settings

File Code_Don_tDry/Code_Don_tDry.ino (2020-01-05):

/*Bonjour et bienvenue sur le code du projet don't dry, tout est commenté et vous pouvez retrouver toutes les recherches du projet sur le git d'eceborg: https://github.com/ECEBORG
Ce code a été réalisé par Nicolas Chollet en Décembre 2019*/


/* Librairies à inclure pour le fonctionnement du projet*/
#include <Adafruit_SSD1306.h> //Bibliothèque de fonctions pour l'écran Oled 128x64
#include <DHT.h> //Bibliothèque de fonctions pour le capteur de température et d'humidité DT11
#include <NTPClient.h> //Bibliothèque de fonction pour la récupération de l'heure sur un serveur NTP
#include <ESP8266WiFi.h> //Bibliothèque de fonction pour la connexion à internet
#include <WiFiUdp.h>  //Bibliothèque de fonction pour la connexion à internet
#include <WiFiClient.h>  //Bibliothèque de fonction pour la connexion à internet
#include <ESP8266WebServer.h>  //Bibliothèque de fonction pour la connexion à internet

/*Ci dessous les Bitmaps: PAS DE PANIQUE il s'agit juste des images logo de l'ECE Paris et d'ECEborg. Si vous voulez changez ou rajouter des images le tutoriel à suivre: https://projetsdiy.fr/ssd1306-mini-ecran-oled-i2c-128x64-arduino/ */

const unsigned char bitmap_ECEBORG[] PROGMEM = {
  B11111111,B11111111,B11111111,B11111111,B11111111,B11111111,B11111111,B11111111,B11111111,B11111111,B11111111,B11111111,B11111111,B11111111,B11111111,B11111111, // ################################################################################################################################
  B11111111,B11111111,B11111111,B11111111,B11111111,B11111111,B11111111,B11111111,B11111111,B11111111,B11111111,B11111111,B11111111,B11111111,B11111111,B11111111, // ################################################################################################################################
  B11111111,B11111111,B11111111,B11111111,B11111111,B11111111,B11111111,B11111111,B11111111,B11111111,B11111111,B11111111,B11111111,B11111111,B11111111,B11111111, // ################################################################################################################################
  B11111111,B11111111,B11111111,B11111111,B11111111,B11111111,B11111111,B11111111,B11111111,B11111111,B11111111,B11111111,B11111111,B11111111,B11111111,B11111111, // ################################################################################################################################
  B11111111,B11111111,B11111111,B11111111,B11111111,B11111111,B11111111,B11111111,B11111111,B11111111,B11111111,B11111111,B11111111,B11111111,B11111111,B11111111, // ################################################################################################################################
  B11111111,B11111111,B11111111,B11111111,B11111111,B11111111,B11111111,B11111111,B11111111,B11111111,B11111111,B11111111,B11111111,B11111111,B11111111,B11111111, // ################################################################################################################################
  B11111111,B11111111,B11111111,B11111111,B11111111,B11111111,B11111111,B11111111,B11111111,B11111111,B11111111,B11111111,B11111111,B11111111,B11111111,B11111111, // ################################################################################################################################
  B11111111,B11111111,B11111111,B11111111,B11111111,B11111111,B11111111,B11111111,B11111111,B11111111,B11111111,B11111111,B11111111,B11111111,B11111111,B11111111, // ################################################################################################################################
  B11111111,B11111111,B11111111,B11111111,B11111111,B11111111,B11111111,B11111111,B11111111,B11111111,B11111111,B11111111,B11111111,B11111111,B11111111,B11111111, // ################################################################################################################################
  B11111111,B11111111,B11111111,B11111111,B11111111,B11111111,B11111111,B11111111,B11111111,B11111111,B11111111,B11111111,B11111111,B11111111,B11111111,B11111111, // ################################################################################################################################
  B11111111,B11111111,B11111111,B11111111,B11111111,B11111111,B11111111,B11111111,B11111111,B11111111,B11111111,B11111111,B11111111,B11111111,B11111111,B11111111, // ################################################################################################################################
  B11111111,B11111111,B11111111,B11111111,B11111111,B11111111,B11111111,B11111111,B11111111,B11111111,B11111111,B11111111,B11111111,B11111111,B11111111,B11111111, // ################################################################################################################################
  B11111111,B11111111,B11111111,B11111111,B11111111,B11111111,B11111111,B11111111,B11111111,B11111111,B11111111,B11111111,B11111111,B11111111,B11111111,B11111111, // ################################################################################################################################
  B11111111,B11111111,B11111111,B11111111,B11111111,B11111111,B11111111,B11111111,B11111111,B11111111,B11111111,B11111111,B11111111,B11111111,B11111111,B11111111, // ################################################################################################################################
  B11111111,B11111111,B11111111,B11111111,B11111111,B11111111,B11111111,B11111111,B11111111,B11111111,B11111111,B11111111,B11111111,B11111111,B11111111,B11111111, // ################################################################################################################################
  B11111111,B11111111,B11111111,B11111111,B11111111,B11111111,B11111111,B11111111,B11111111,B11111111,B11111111,B11111111,B11111111,B11111111,B11111111,B11111111, // ################################################################################################################################
  B11111111,B11111111,B11111111,B11111111,B11111111,B11111111,B11111111,B11111111,B11111111,B11111111,B11111111,B11111111,B11111111,B11111111,B11111111,B11111111, // ################################################################################################################################
  B11111111,B11111111,B11111111,B11111111,B11111111,B11111111,B11111111,B11111111,B11111111,B11111111,B11111111,B11111111,B11111111,B11111111,B11111111,B11111111, // ################################################################################################################################
  B11111111,B11111111,B11111111,B11111111,B11111111,B11111111,B11111111,B11111111,B11111111,B11111111,B11111111,B11111111,B11111111,B11111111,B11111111,B11111111, // ################################################################################################################################
  B11111111,B11100000,B00000011,B11100000,B00000011,B11000000,B00000111,B00000000,B00011111,B10000000,B00111110,B00000000,B00111111,B00000000,B00011111,B11111111, // ###########...........#####...........####...........###...........######.........#####...........######...........#############
  B11111111,B11100000,B00000011,B11000000,B00000011,B11000000,B00000111,B00000000,B00001111,B00000000,B00011110,B00000000,B00011110,B00000000,B00011111,B11111111, // ###########...........####............####...........###............####...........####............####............#############
  B11111111,B11000000,B00000011,B11000000,B00000011,B10000000,B00000111,B00000000,B00001111,B00000000,B00001110,B00000000,B00011110,B00000000,B00011111,B11111111, // ##########............####............###............###............####............###............####............#############
  B11111111,B11000000,B00000011,B11000000,B00000011,B10000000,B00000111,B00000000,B00000111,B00000000,B00001110,B00000000,B00011110,B00000000,B00011111,B11111111, // ##########............####............###............###.............###............###............####............#############
  B11111111,B11000111,B11100011,B11111111,B11110111,B10001111,B10000111,B11111111,B10000111,B00011110,B00001111,B11111111,B00011111,B11111111,B10111111,B11111111, // ##########...######...##############.####...#####....############....###...####.....############...##############.##############
  B11111111,B11000111,B11111111,B11111111,B11111111,B10001111,B11111111,B11111111,B11000111,B00111111,B10001111,B11111111,B10011111,B11111111,B11111111,B11111111, // ##########...############################...######################...###..#######...#############..#############################
  B11111111,B11000111,B11111111,B11111111,B11111111,B10001111,B11111111,B11111111,B11000111,B00111111,B10001111,B11111111,B10011111,B11111111,B11111111,B11111111, // ##########...############################...######################...###..#######...#############..#############################
  B11111111,B11000111,B11111111,B11111111,B11111111,B10001111,B11111111,B11111111,B11000111,B00111111,B10001111,B11111111,B10011111,B11111111,B11111111,B11111111, // ##########...############################...######################...###..#######...#############..#############################
  B11111111,B11000110,B00001111,B11001111,B11111111,B10001100,B00011111,B10000000,B00001111,B00111001,B10001111,B00000000,B00011110,B01110000,B00111111,B11111111, // ##########...##.....######..#############...##.....######...........####..###..##...####...........####..###......##############
  B11111111,B11000110,B00001111,B10001111,B11111111,B10001100,B00011111,B00000000,B00001111,B00111001,B10001110,B00000000,B00011110,B01100000,B00011111,B11111111, // ##########...##.....#####...#############...##.....#####............####..###..##...###............####..##........#############
  B11111111,B11000110,B00001111,B10001111,B11111111,B10001100,B00011111,B00000000,B00001111,B00111001,B10001110,B00000000,B00011110,B01100000,B00011111,B11111111, // ##########...##.....#####...#############...##.....#####............####..###..##...###............####..##........#############
  B11111111,B11000110,B00001111,B10001111,B11111111,B10001100,B00011111,B00000000,B00001111,B00111001,B10001110,B00000000,B00011110,B01100000,B00011111,B11111111, // ##########...##.....#####...#############...##.....#####............####..###..##...###............####..##........#############
  B11111111,B11000110,B00001111,B10001111,B11111111,B10001100,B00111111,B00000000,B00001111,B00111001,B10001110,B00000000,B00011110,B01110000,B00011111,B11111111, // ##########...##.....#####...#############...##....######............####..###..##...###............####..###.......#############
  B11111111,B11000111,B11111111,B10001111,B11111111,B10001111,B11111111,B00011111,B11000111,B00111111,B10001110,B00111111,B10011110,B01111111,B00011111,B11111111, // ##########...############...#############...############...#######...###..#######...###...#######..####..#######...#############
  B11111111,B11000111,B11111111,B10001111,B11111111,B10001111,B11111111,B00011111,B11000111,B00111111,B10001110,B00111111,B10011110,B01111111,B00011111,B11111111, // ##########...############...#############...############...#######...###..#######...###...#######..####..#######...#############
  B11111111,B11000111,B11111111,B10001111,B11111111,B10001111,B11111111,B00011111,B11000111,B00111111,B10001110,B00111111,B10011110,B01111111,B00011111,B11111111, // ##########...############...#############...############...#######...###..#######...###...#######..####..#######...#############
  B11111111,B11000000,B00000011,B10000000,B00000111,B10000000,B00001111,B00000011,B10000111,B00011111,B10001110,B00111111,B10011110,B00111111,B00011111,B11111111, // ##########............###............####...........####......###....###...######...###...#######..####...######...#############
  B11111111,B11000000,B00000011,B10000000,B00000011,B10000000,B00000111,B00000000,B00000111,B00000000,B00001110,B00111111,B10011110,B00000000,B00011111,B11111111, // ##########............###.............###............###.............###............###...#######..####............#############
  B11111111,B11000000,B00000011,B11000000,B00000011,B10000000,B00000111,B00000000,B00001111,B00000000,B00001110,B00111111,B10011110,B00000000,B00011111,B11111111, // ##########............####............###............###............####............###...#######..####............#############
  B11111111,B11100000,B00000011,B11000000,B00000011,B11000000,B00000111,B00000000,B00001111,B10000000,B00011110,B00111111,B10011110,B00000000,B00111111,B11111111, // ###########...........####............####...........###............#####..........####...#######..####...........##############
  B11111111,B11110000,B00000011,B11100000,B00000011,B11000000,B00000111,B10000000,B00011111,B10000000,B00111111,B00111111,B10011111,B00000000,B01111111,B11111111, // ############..........#####...........####...........####..........######.........######..#######..#####.........###############
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
};
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
void loop() {
/*Si une requete arrive il affiche la page*/
server.handleClient();
  
  display.clearDisplay();
  display.setTextSize(2);
  display.setTextColor(WHITE);
  display.setCursor(0,0);

  /*Lecture des valeurs */
  h = dht.readHumidity();
  t = dht.readTemperature();
  // t=t-3;
  
 
  /*Si on arrive pas à lire le DHT 11
  if (isnan(h) || isnan(t)) {
    display.println("Failed to read from DHT sensor!");
    display.display();
    display.clearDisplay();
    return;
  }*/

  /*Lecture de la valeur du sol et affichage en serial*/
  soilValue = analogRead(A0);
  Serial.println(soilValue);

  
/*On affiche les valeurs */
  display.print(" T:");
  display.print(t);
  display.println(" C");
  // Humidité en % - Humidity in % 
  display.print(" H:");
  display.print(h);
  display.println(" %");
  display.print("Soil: ");
  
  /************************************/
  /*Ici il faut potentiellement ajuster les valeurs pour adapter au pot de la plante: les valeurs vont de 0 à 1024 plus la valeur est haute plus le sol est sec
  Il faut choisir deux valeurs: la valeurs à laquelle le capteur nous dit d'arroser et la valeur a laquelle le sol est trop mouillé*/
  if(soilValue>800){display.print("HELP");}
  else if(soilValue>=100){display.print(" OK");}
  else if(soilValue<100){display.print(" Wet");}
  /****************************/

/*Affichage de l'heure si connecté à la wifi*/
   if(WiFi.status() == WL_CONNECTED){
    timeClient.update();
    display.print("   ");
    if(timeClient.getHours()<10){display.print("0");}
    display.print(timeClient.getHours());
    display.print(":");
    if(timeClient.getMinutes()<10){display.print("0");}
    display.println(timeClient.getMinutes());
   }
  
  display.display();

  /*Délais entre deux relevé*/
  delay(1000);
  
}
  
